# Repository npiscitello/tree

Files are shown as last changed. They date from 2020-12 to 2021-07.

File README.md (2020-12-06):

# tree
Code for a blinky palm tree, which is really just a long strip of fairy lights
bent up in the shape of a palm tree. The fairy lights are wired as a bunch of
parallel LEDs with alternating polarity, so by switching the polarity, you
switch the set of lights that are lit. Poke some MOSFETs into an ATMEGA328 and
you have yourself some good old-fashioned blinkenlight!

Check out [avr-libc] (https://nongnu.org/avr-libc/) for the libs I use.

# dimming profiles
I decided I didn't like a strictly linear dim, so I played around with some
custom dimming profiles, implemented as a lookup table. Turns out, it starts
looking weird if you stray too far from linear, so I settled on the
circular_mod profile. This is, of course, for my sister, so if she doesn't like
it I'll keep tweaking! See the ODS spreadsheet for calculation details.
Remember, since we're using inverted PWM, an output of 255 is off and 0 is
fully on.
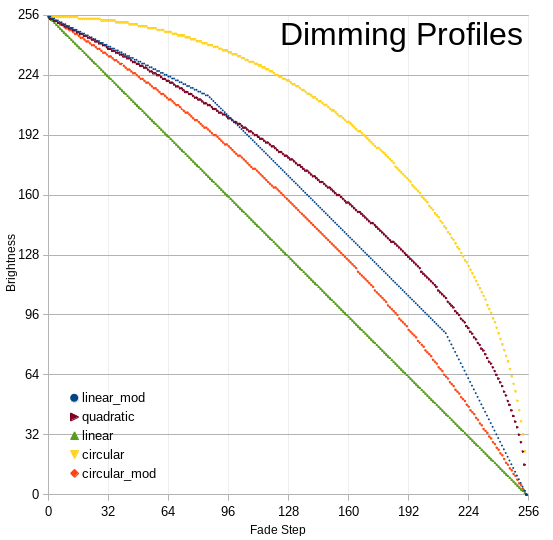
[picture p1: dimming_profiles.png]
dimming profile plot


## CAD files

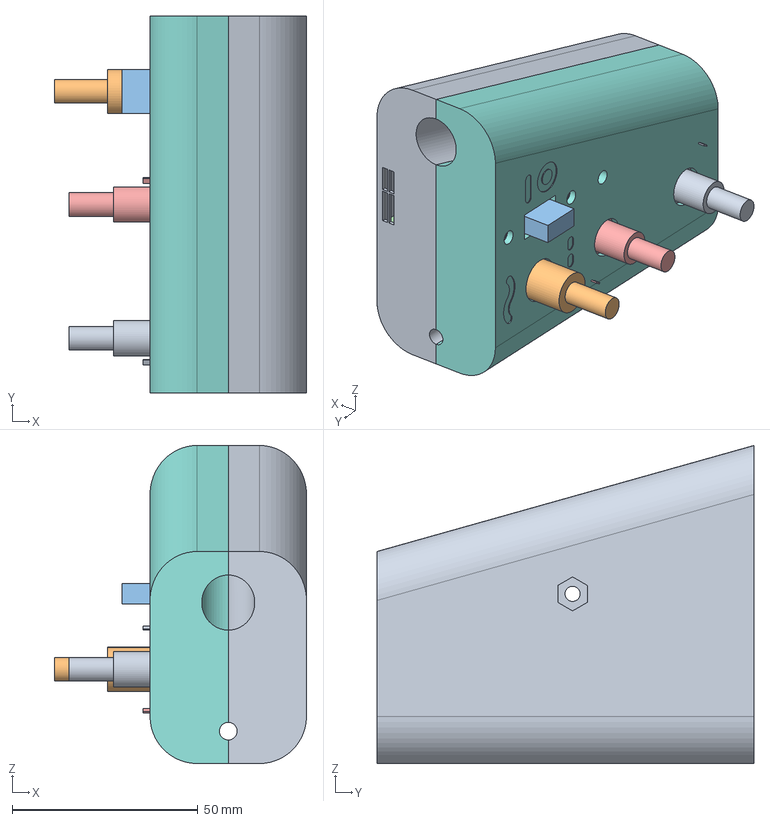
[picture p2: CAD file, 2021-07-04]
enclosure.FCStd
67.9 x 101.6 x 85.7 mm
pot_bright
modesw
pwrsw
board
pot_speed
pwrconn
ledconn
clamshell_a
clamshell_b

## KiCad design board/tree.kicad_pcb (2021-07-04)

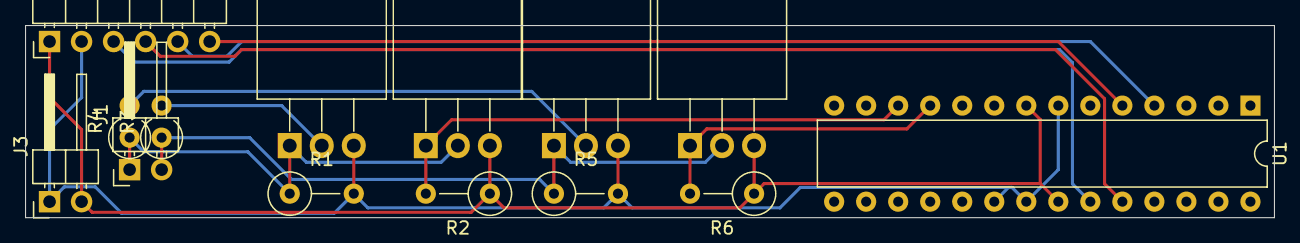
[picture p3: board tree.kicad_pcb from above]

Board: 2 copper layers, 99.1 x 15.2 mm, 14 parts (0 on the bottom side), 12 nets.

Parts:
J1: LED; PinHeader_1x02_P2.54mm_Horizontal
J2: panel; PinHeader_1x06_P2.54mm_Horizontal
J3: PWR; PinHeader_1x02_P2.54mm_Horizontal
Q1, Q3: PMOS; TO-220-3_Horizontal_TabDown
Q2, Q4: NMOS; TO-220-3_Horizontal_TabDown
R1, R2, R5, R6: 33k; R_Axial_DIN0309_L9.0mm_D3.2mm_P5.08mm_Vertical
R3, R4: 10; R_Axial_DIN0309_L9.0mm_D3.2mm_P2.54mm_Vertical
U1: ATmega328-PU; DIP-28_W7.62mm

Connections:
+5V: J2.2, J3.1, Q1.3, Q3.3, R1.2, R5.2, U1.7, U1.20, U1.21
/blink: J2.6, U1.5
/bright: J2.3, U1.23
/fade: J2.5, U1.4
/led_A: Q2.1, R2.2, U1.12
/led_B: Q4.1, R6.2, U1.11
/speed: J2.4, U1.24
GND: J2.1, J3.2, Q2.3, Q4.3, R2.1, R6.1, U1.8, U1.22
unnamed: J1.1, Q1.1, Q2.2, R1.1, R4.1
unnamed: J1.2, Q3.1, Q4.2, R3.1, R5.1
unnamed: Q1.2, R3.2
unnamed: Q3.2, R4.2

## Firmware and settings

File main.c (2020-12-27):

#include "avr/io.h"
#include "avr/interrupt.h"
#include "fade_table.h"

// timing data for timer1 (driving blinking/fading speed)
#define BLINK_DELAY_MIN   (7812.5 * 0.075)  // 0.075 sec/blink
#define BLINK_DELAY_MAX   (7812.5 * 2)      // 2 sec/blink
#define FADE_DELAY_MULT   15                // we multiply the delay val by
                                            // this to get the total fade time
                                            // in milliseconds
#define FADE_DURATION_MIN 300               // minimum full fade duration, ms
// duration max = FADE_DURATION_MIN + FADE_DELAY_MULT * maximum bright_val (256)
#define FADE_TMR_FREQ     31250             // timer1 freq for fade ops
#define DELAY_RES         (uint16_t)256     // number of possible values
                                            // for the delay variable

// in/out definitions
#define PORT_LEDB     PORTD5
#define DD_LEDB       DDD5
#define PORT_LEDA     PORTD6
#define DD_LEDA       DDD6
#define PORT_FADE     PORTD2
#define DD_FADE       DDD2
#define PIN_FADE      PIND2
#define PORT_BLINK    PORTD3
#define DD_BLINK      DDD3
#define PIN_BLINK     PIND3

// so we don't waste a whole byte every time we need a bool
volatile uint8_t flags = 0x00;
#define F_MODE_CHANGED    7
#define F_TIMER1_TRIG     6
#define F_ADC_DONE        5
#define F_LED_BANK        4
#define F_PATTERN_BIT     3

// ADC buffers
// PWM is inverting, so 0 = full bright, 255 = off
#define BRIGHT_OFF  255
volatile uint8_t bright_val = BRIGHT_OFF;
volatile uint8_t delay_val = 0;
volatile uint8_t* adc_reg = &bright_val;

// LED bank brightness buffers for TIMER0 ISR
volatile uint8_t ledA_bright = BRIGHT_OFF;
volatile uint8_t ledB_bright = BRIGHT_OFF;

// INT0/INT1 ISRs - mode switch changed
ISR(INT0_vect) {
  flags |= _BV(F_MODE_CHANGED);
}
ISR(INT1_vect, ISR_ALIASOF(INT0_vect));

// timer 0 ISR - swap LED banks
ISR(TIMER0_OVF_vect) {
  // We're splitting time between the LED strings - each string does one
  // on/off cycle then spends an entire PWM period off while the other
  // string does its cycle. This effectively halves the PWM freq.
  if( flags & _BV(F_LED_BANK) ) {
    OCR0A = BRIGHT_OFF;
    OCR0B = ledB_bright;
  } else {
    OCR0A = ledA_bright;
    OCR0B = BRIGHT_OFF;
  }
  flags ^= _BV(F_LED_BANK);
}

// timer 1 ISR - set flag for pattern loop
ISR(TIMER1_COMPA_vect) {
  flags |= _BV(F_TIMER1_TRIG);
}

// timer 2 ISR - swap ADC regs and trigger an ADC conversion
ISR(TIMER2_COMPA_vect) {
  if( adc_reg == &bright_val ) {
    adc_reg = &delay_val;
    ADMUX = (ADMUX & 0xF0) | _BV(MUX0);
  } else {
    adc_reg = &bright_val;
    ADMUX = (ADMUX & 0xF0);
  }
  ADCSRA |= _BV(ADSC);
}

// ADC done ISR - write out result
ISR(ADC_vect) {
  flags |= _BV(F_ADC_DONE);
  *adc_reg = ADCH;
}

int main(void) {
  // set up inputs/outputs
  // main LEDs: output, OC0A/OC0B (PD5/PD6)
  // fade trigger: input, pullup, INT0 (PD2)
  // blink trigger: input, pullup, INT1 (PD3)
  DDRD = _BV(DD_LEDA) | _BV(DD_LEDB);
  PORTD = _BV(PORT_FADE) | _BV(PORT_BLINK);

  // drop the clock to 2MHz to support a better PWM freq
  // test compatibility on final board;
  CLKPR = _BV(CLKPCE);
  CLKPR = _BV(CLKPS1);

  // turn on what we need, turn off what we don't
  //  - Timer 0: output PWM
  //  - Timer 1: blink/fade delay timing
  //  - Timer 2: ADC management
  //  - ADC: read delay time/brightness potentiometer
  PRR = ~_BV(PRTIM0) & ~_BV(PRTIM1) & ~_BV(PRTIM2) & ~_BV(PRADC);

  // enable interrupts for switch, timers, and ADC
  EICRA = _BV(ISC10) | _BV(ISC00);
  EIMSK = _BV(INT1) | _BV(INT0);
  asm("sei");

  // set up ADC in oneshot mode and left adjust the result
  ADMUX = _BV(ADLAR);
  // sys/16, 125kHz tick
  ADCSRA = _BV(ADIE) | _BV(ADPS2);
  ADCSRA |= _BV(ADEN);

  // set up PWM on timer 0
  // fast PWM, 8 bit resolution, both outputs inverting (inverting allows us
  // to turn an output completely off using only the OCR0X register)
  TCCR0A = _BV(WGM01) | _BV(WGM00) |
    _BV(COM0A1) | _BV(COM0A0) | _BV(COM0B1) | _BV(COM0B0);
  // sys/8, 250kHz clock, ~976Hz PWM freq, ~488 effective PWM freq
  // (see ISR, PWM freq is halved because we split time between banks)
  TCCR0B = _BV(CS01);               // sys/8
  // interrupt on every PWM cycle
  TIMSK0 = _BV(TOIE0);

  // set up pattern timing on timer1
  // compare match interrupt
  TIMSK1 = _BV(OCIE1A);

  // set up ADC switching on timer 2
  // CTC
  TCCR2A = _BV(WGM21);
  // enable interrupts
  TIMSK2 = _BV(OCIE2A);
  // sys/32, 62.5kHz tick, OCR2A of 31 yields ~2016 triggers/sec
  // At the ADC clock of 125kHz, that allows 62 ADC clocks per trigger
  OCR2A = 31;
  TCCR2B = _BV(CS21) | _BV(CS20);

  while( 1 ) {
// fade setup //
    if( !(PIND & _BV(PIN_FADE)) ) {
      // timer 1 resets on every brightness level change (256 per fade), 
      // so we run it fast
      // CTC, sys/64, 31.25kHz tick, max delay possible 0.5 sec (537 sec fade)
      TCCR1B = _BV(WGM12) | _BV(CS11) | _BV(CS10);
      // turn on right away
      flags |= _BV(F_TIMER1_TRIG);
      // store fade states
      uint8_t total_steps = 0;
      uint8_t fade_step = 0;

// fade loop //
      while(1) {
        if( flags & _BV(F_ADC_DONE) ) {
          flags &= ~_BV(F_ADC_DONE);
          // total number of fade steps is based off of the peak brightness
          total_steps = BRIGHT_OFF - bright_val;
          // Constant time fade - fade takes the same amount of time regardless
          // of brightness, meaning slow, dim fades will have low resolution.
          // This also means the number of ticks per fade step depends on both
          // the desired speed and the desired peak brightness.
          OCR1A = FADE_TMR_FREQ * 
            (FADE_DURATION_MIN + ((uint16_t)delay_val * FADE_DELAY_MULT)) / 
            total_steps;
          if( (uint16_t)TCNT1 > (uint16_t)OCR1A ) {
            // we've missed the compare, fake a match and start over
            flags |= _BV(F_TIMER1_TRIG);
            TCNT1 = 0x0000;
          }
        }
        if( flags & _BV(F_TIMER1_TRIG) ) {
          flags &= ~_BV(F_TIMER1_TRIG);
          if( fade_step >= total_steps) {
            flags ^= _BV(F_PATTERN_BIT);
            fade_step = 0;
          }
          // fade according to a pre-calculated profile
          if( flags & _BV(F_PATTERN_BIT) ) {
            ledA_bright = get_brightness(CIRCULAR_MOD, total_steps-fade_step);
            ledB_bright = get_brightness(CIRCULAR_MOD, fade_step);
          } else {
            ledA_bright = get_brightness(CIRCULAR_MOD, fade_step);
            ledB_bright = get_brightness(CIRCULAR_MOD, total_steps-fade_step);
          }
          fade_step++;
        }
        if( flags & _BV(F_MODE_CHANGED) ) break;
      }

// blink setup //
    } else if( !(PIND & _BV(PIN_BLINK)) ) {
      // timer 1 resets when the LED bank should switch, so we run it very slow
      // CTC, sys/256, 7812.5Hz tick, max delay possible 8.39 secs
      TCCR1B = _BV(WGM12) | _BV(CS12);
      // turn on right away
      flags |= _BV(F_TIMER1_TRIG);
      // aliases to the reg currently doing its blink duty
      volatile uint8_t* on_reg = &ledA_bright;

// blink loop //
      while(1) {
        if( flags & _BV(F_ADC_DONE) ) {
          flags &= ~_BV(F_ADC_DONE);
          *on_reg = bright_val;
          OCR1A = BLINK_DELAY_MIN + 
            (((BLINK_DELAY_MAX - BLINK_DELAY_MIN) /
              DELAY_RES) * (uint16_t)delay_val);
          if( (uint16_t)TCNT1 > (uint16_t)OCR1A ) {
            // we've missed the compare, fake a match and start over
            flags |= _BV(F_TIMER1_TRIG);
            TCNT1 = 0x0000;
          }
        }
        if( flags & _BV(F_TIMER1_TRIG) ) {
          flags &= ~_BV(F_TIMER1_TRIG);
          flags ^= _BV(F_PATTERN_BIT);
          if( flags & _BV(F_PATTERN_BIT) ) {
            ledA_bright = BRIGHT_OFF;
            on_reg = &ledB_bright;
          } else {
            on_reg = &ledA_bright;
            ledB_bright = BRIGHT_OFF;
          }
        }
        if( flags & _BV(F_MODE_CHANGED) ) break;
      }

// steady on setup //
    } else {

// steady on loop //
      while(1) {
        if( flags & _BV(F_ADC_DONE) ) {
          flags &= ~_BV(F_ADC_DONE);
          ledA_bright = bright_val;
          ledB_bright = bright_val;
        }
        if( flags & _BV(F_MODE_CHANGED) ) break;
      }
    }
    flags &= ~_BV(F_MODE_CHANGED);
  }

  // we should never get here!
  return 0;
}

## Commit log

2020-11-28 added ADC swapping to prep for speed control for patterns
    [main.c]
2020-11-29 trying a restructure, getting very weird errors. Commiting so I can revert and see if they're present previously
    [main.c]
2020-11-29 back to working - problem was a lack of understanding of how PWM works
    [main.c]
2020-11-29 Trying a slower clock (2MHz)
    This will allow a PWM freq of 976, doubled from previous, and an
    effective PWM freq of 488 - high enough to avoid flickering and low
    enough to play nice with the MOSFETs. Hopefully. This is something
    that'll just have to be tested on the final board.
    Also reassigned bank switching duty to the TIM0 interrupt.
    [main.c]
2020-11-29 seems to glitch out unless blink is run first...
    [main.c]
2020-12-05 tried math-based variable rate fade, too slow; going to a lookup table
    [main.c]
2020-12-06 lookup-driven fade is working! Code should be done, just need to make a board and test it
    [lookup_table_calculator.ods]
2020-12-06 docs...of a sort
    [lookup_table_calculator.ods]
2020-12-27 just cleaning up - was chasing an error that ended up being a lack of a filter cap -.-
    [main.c]
2021-07-04 added physcial designs
    [enclosure.FCStd, tree.kicad_pcb, tree.sch]
